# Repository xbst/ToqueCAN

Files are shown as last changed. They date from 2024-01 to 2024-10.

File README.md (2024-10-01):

# 

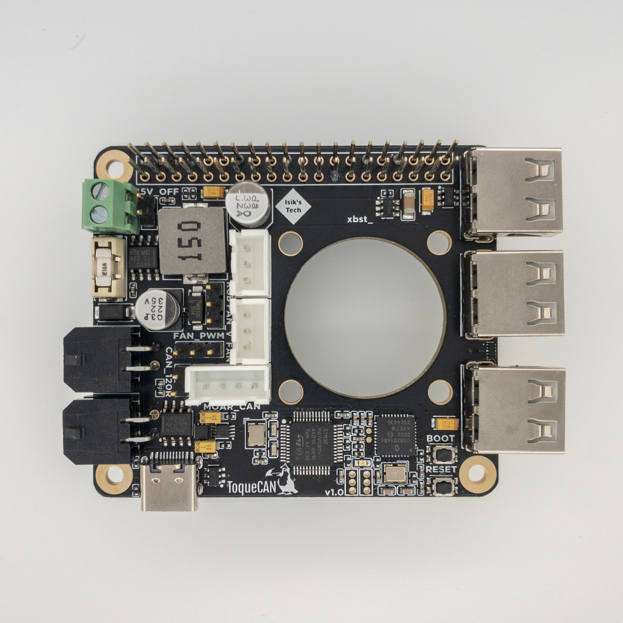
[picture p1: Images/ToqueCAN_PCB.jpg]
ToqueCAN PCB


ToqueCAN is an open-source Raspberry Pi toque* with:
- A CAN transceiver with 2x CAN connectors
- 3 port USB hub
- 24V to 5V 5A regulator for powering the Pi and USB devices
- Pi cooling fan (30mm or 40mm) mount with PWM speed control
- Neopixel control
- GPIO passthrough
- Supports Klipper and Candlelight firmwares

Designed for 3D printers with many CAN devices, 24V power and small electronics chambers.

*Almost like a hat, no EEPROM.

## YouTube Video
YouTube Video (https://youtu.be/QP4bZ6_RnH0)

## Purchasing a ToqueCAN
### Buy From Me
- Each PCB tested by me
- All connectors needed are included (if applicable)
- Supports the development of open-source projects like this
- Ships worldwide

#### United States
- [Isik's Tech](https://store.isiks.tech/products/toquecan)

### Resellers
- Each PCB tested by me
- All connectors needed are included (if applicable)
- Supports the development of open-source projects like this
#### United States
- [Amazon - Prime Shipping](https://www.amazon.com/dp/B0D33F7GBZ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)
- [West3D](https://west3d.com/products/toquecan-pi-toque-with-2xcan-and-24v-5v-regulator?_pos=1&_psq=Toque&_ss=e&_v=1.0)
#### Canada
- [Amazon - Ships from the US](https://www.amazon.ca/dp/B0D33F7GBZ)
#### European Union
- [Lab4450 - Portugal](https://lab4450.com/product/toquecan-pi-by-xbst_/)

### Other Trusted Vendors
These vendors source their PCBs from other sources, but are trusted vendors on Voron and Voron-related communities.

[TBD]

This project is licensed under [GPL v3](./LICENSE), meaning vendors are allowed to sell PCBs without paying me. If you'd like to support the development of this and future projects please consider [sponsoring](https://github.com/sponsors/xbst) me on GitHub. You can also subscribe on [Patreon](https://l.isiks.tech/patreon) or [YouTube](https://l.isiks.tech/member).

You can also use the included gerber files to order your own from a PCB manufacturer like [PCBWay](https://www.pcbway.com/setinvite.aspx?inviteid=374841) or [JLCPCB](https://jlcpcb.com/).
<br>

## [Instructions](./Docs/ToqueCAN-Manual.pdf)
Click the above link to download the ToqueCAN manual (PDF).

## YouTube

I am a YouTube content creator. If you want content about these projects & more, please consider [subscribing to my YouTube channel](https://www.youtube.com/channel/UClAWYmCkHjsbaX9Wz1df2mg).
<br>

If you feel like contributing to the development of this project and other projects like this you can sponsor me on [GitHub](https://github.com/sponsors/xbst), subscribe on [Patreon](https://l.isiks.tech/patreon) or [YouTube](https://l.isiks.tech/member).

## Notes
- Markdown files in this repository may contain Amazon Associate, Aliexpress affiliate, PCBWay affiliate, Jawstec affiliate, Polymaker affiliate links. I make a comission on qualifying purchases.
- This project does not come with any warranty, if you choose to build/use a PCB manufactured using published files in this repository, you are doing this at your own risk!
- If you want to sell PCBs manufactured using published files in this repository, you are allowed to, and you will not owe me any royalties. **You cannot claim that I endorse the sale**. You can check the license file for more information. However, if you **wish** to give me a share you can sponsor me on [GitHub](https://github.com/sponsors/xbst), subscribe on [Patreon](https://l.isiks.tech/patreon) or [YouTube](https://l.isiks.tech/member).

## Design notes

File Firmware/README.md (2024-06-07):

Only for Klipper in bridge mode. Follow the [documentation](../Docs/ToqueCAN-Manual.pdf) for more info.

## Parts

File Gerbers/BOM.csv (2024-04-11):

ID | Name | Designator | Footprint | Quantity | Manufacturer Part | Manufacturer | Supplier | Supplier Part | Price
1 | 10u | C17,C19,C13 | CAP-SMD_L3.2-W1.6-R-RD | 3 | TAJA106K016RNJ | AVX | LCSC | C7171 | 0.097
2 | 5.1kΩ | R7,R8 | R0402 | 2 | RC0402FR-075K1L | YAGEO(国巨) | LCSC | C105872 | 0.001
3 | 3.16kΩ | R10 | R0402 | 1 | 0402WGF3161TCE | UNI-ROYAL(厚声) | LCSC | C11462 | 0.001
4 | 43045-0401 | CAN1,CAN2 | CONN-TH_0430450400 | 2 | 43045-0401 | MOLEX | LCSC | C585880 | 0.689
5 | XH-4A-B | MOAR_CAN | CONN-TH_B4B-XH-A-BK-LF-SN | 1 | XH-4A | HCTL | LCSC | C37815 | 0.027
6 | PUSB3F96X_C2923351 | D5 | DFN2510-10_L2.5-W1.0-P0.50-BL | 1 | PUSB3F96X | TECH PUBLIC(台舟) | LCSC | C2923351 | 0.089
7 | USBLC6-2SC6_C2827654 | D4,D3 | SOT-23-6_L2.9-W1.6-P0.95-LS2.8-BL | 2 | USBLC6-2SC6 | TECH PUBLIC(台舟) | LCSC | C2827654 | 0.058
8 | U-A-24DD-W-5 | USB2,USB1,USB3 | USB-A-TH_U-A-24DD-W-5 | 3 | U-A-24DD-W-5 | 韩国韩荣 | LCSC | C530625 | 0.094
9 | 1uF | C20,C21 | CASE-A_3216 | 2 | CA45-A-35V-1uF-K | CEC(振华新云) | LCSC | C141744 | 0.089
10 | 100n | C22,C23,C24,C25,C26,C27,C3,C5,C7,C10,C11,C12 | C0402 | 12 |  |  | LCSC | C1525 | 0.001
11 | 0154010.DR | F1 | FUSE-SMD_L9.7-W5.0 | 1 | 0154010.DR | Littelfuse(美国力特) | LCSC | C206921 | 1.346
12 | B3B-XH-A-BK(LF)(SN) | FAN,RGB | CONN-TH_3P-P2.50_B3B-XH-A-BK-LF-SN | 2 | B3B-XH(LF)(SN) | JST | LCSC | C144394 | 0.089
13 | HDR-M-2.54_1x3 | FAN_PWM,FAN_V | HDR-M-2.54_1X3 | 2 |  |  | LCSC | C306138 | 0.2
14 | 10K 1% | R18,R1,R9 | R0402 | 3 |  |  | LCSC | C25744 | 0.001
15 | SN74LVC2G125DCUR | U4 | VSON8_L2.0-W2.3-P0.50-LS3.1-BL | 1 | SN74LVC2G125DCUR | TI(德州仪器) | LCSC | C21404 | 0.258
16 | LP5912-3.3DRVR | U7 | WSON-6_L2.0-W2.0-P0.65-TL-EP | 1 | LP5912-3.3DRVR | TI(德州仪器) | LCSC | C524780 | 0.695
17 | 8MHz | X1 | CRYSTAL-SMD_4P-L3.2-W2.5-BL-2 | 1 | 3TJ480000ZYLBC | JYJE(晶友嘉) | LCSC | C2924619 | 0.195
18 | 15uH | L1 | IND-SMD_L10.1-W11.6 | 1 | CKST1004-15uH/M | CENKER | LCSC | C3002687 | 0.262
19 | DB125-3.5-2P-GN-S | VIN | CONN-TH_2P-P3.50_L7.4-W7.0 | 1 | DB125-3.5-2P-GN-S | DIBO(地博电气) | LCSC | C466970 | 0.159
20 | 470R 1% | R16 | R0402 | 1 |  |  | LCSC | C25117 | 0.001
21 | HDR-M-2.54_1x2 | 5V_OFF,CAN_120R | HDR-M-2.54_1X2 | 2 |  |  | LCSC | C180247 | 0.022
22 | EVPAA202K | BOOT,RESET | KEY-SMD_4P-L3.5-W2.9-P1.48-LS4.3-TL | 2 | EVPAA202K | PANASONIC(松下) | LCSC | C79147 | 0.356
23 | 100uF | C1 | C1206 | 1 |  | SAMSUNG(三星) | LCSC | C15008 | 0.063
24 | 22u | C2 | CAP-D6.3×H5.5 | 1 | UWF1V220MCL1GB-W | Nichicon | LCSC | C2163072 | 0.157
25 | 330u | C14 | CAP-D6.3×H5.5 | 1 | EMZA6R3ARA331MF80G | NCC(Nippon Chemi-Con) | LCSC | C2165829 | 0.168
26 | 100nF | C4,C6 | C0402 | 2 | 0402B104K500NT | FH(风华) | LCSC | C110251 | 0.002
27 | 30pF | C8,C9 | C0603 | 2 | 0603CG300J500NT | FH(风华) | LCSC | C1658 | 0.003
28 | 20pF | C15,C16 | C0603 | 2 |  | SAMSUNG(三星) | LCSC | C1648 | 0.005
29 | LED-0603_B | CAN_MCU | LED0603_BLUE | 1 | 19-217/BHC-ZL1M2RY/3T | EVERLIGHT(台湾亿光) | LCSC | C72041 | 0.018
30 | SS34_C8678 | D1 | SMA_L4.3-W2.6-LS5.2-RD | 1 | SS34 | MDD | LCSC | C8678 | 0.023
31 | SS54_C22452 | D2 | SMA_L4.4-W2.8-LS5.4-R-RD | 1 | SS54 | MDD | LCSC | C22452 | 0.038
32 | 27R4 1% | R3,R4 | R0402 | 2 |  |  | LCSC | C31439 | 0.001
33 | 120Ω | R2 | R0603 | 1 | FRC0603F1200TS | FOJAN | LCSC | C2906988 | 0.001
34 | 10Ω | R5 | R0402 | 1 | 0402WGF100JTCE | UNI-ROYAL(厚声) | LCSC | C25077 | 0.001
35 | 1.5kΩ | R6 | R0402 | 1 | 0402WGF1501TCE | UNI-ROYAL(厚声) | LCSC | C25867 | 0.001
36 | 36kΩ | R11,R12,R13,R14 | R0402 | 4 |  | UNI-ROYAL(厚声) | LCSC | C43676 | 0.001
37 | 12kΩ | R15 | R0402 | 1 |  | UNI-ROYAL(厚声) | LCSC | C25752 | 0.001
38 | 15kΩ | R17 | R0402 | 1 |  | UNI-ROYAL(厚声) | LCSC | C25756 | 0.001
39 | TPS5450DDAR | U1 | SOP-8_L4.9-W3.9-P1.27-LS6.0-BL-EP | 1 | TPS5450DDAR | TI(德州仪器) | LCSC | C114425 | 0.772
40 | STM32F072C8T6 | U2 | LQFP-48_L7.0-W7.0-P0.50-LS9.0-BL | 1 | STM32F072CBT6 | ST(意法半导体) | LCSC | C81720 | 1.718
41 | SN65HVD232DR | U3 | SOIC-8_L5.0-W4.0-P1.27-LS6.0-BL | 1 | SN65HVD232DR | TI(德州仪器) | LCSC | C30530 | 0.966
42 | USB2514B-I/M2 | U5 | SQFN-36_L6.0-W6.0-P0.50-BL-EP | 1 | USB2514B-I/M2 | MICROCHIP(美国微芯) | LCSC | C220679 | 2.092
43 | AP22653W6-7 | U6 | SOT-23-6_L2.9-W1.6-P0.95-LS2.8-BR | 1 |  | DIODES(美台) | LCSC | C2158037 | 0.238
44 | USB3.1C16PFSMT | USBCIN | USB-C-SMD_TYPE-C-USB-17 | 1 | - | LCSC | LCSC | C167321 | 0.358
45 | 24MHz | X2 | CRYSTAL-SMD_4P-L3.2-W2.5-BL | 1 |  | TAE(雅晶鑫) | LCSC | C362340 | 0.062
46 | HDR-TH_40P-P2.54-V-F-R2-C20-S2.54-2 | U8 | HDR-TH_40P-P2.54-V-F-R2-C20-S2.54-2 | 1 | 2.54-2*20P母长PC104 | BOOMELE(博穆精密) | LCSC | C35165 | 0.943

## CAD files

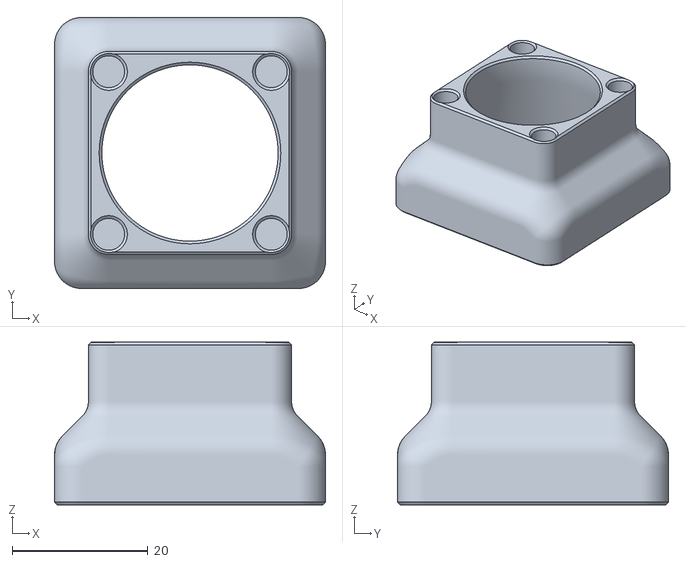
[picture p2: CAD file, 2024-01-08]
Fan-Mounts/40mm_Fan_Holder.stl
40.0 x 40.0 x 24.0

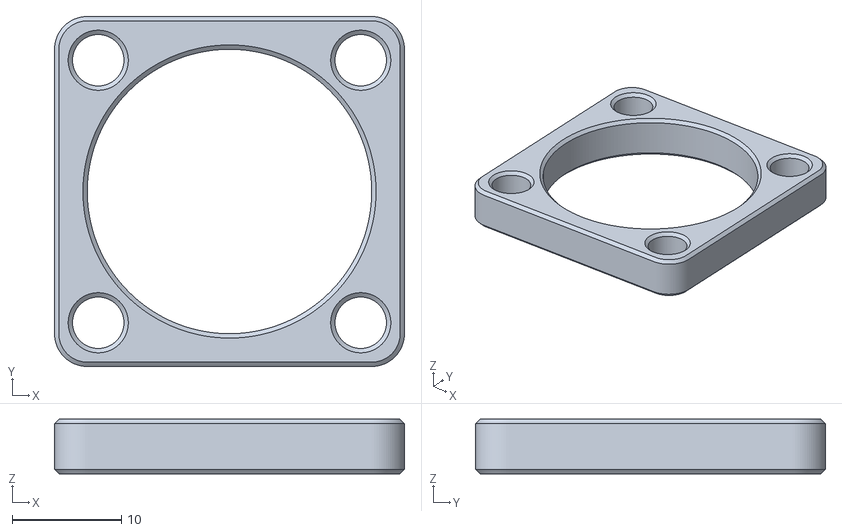
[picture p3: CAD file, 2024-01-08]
Fan-Mounts/30mm_Fan_Holder.stl
32.0 x 32.0 x 5.00

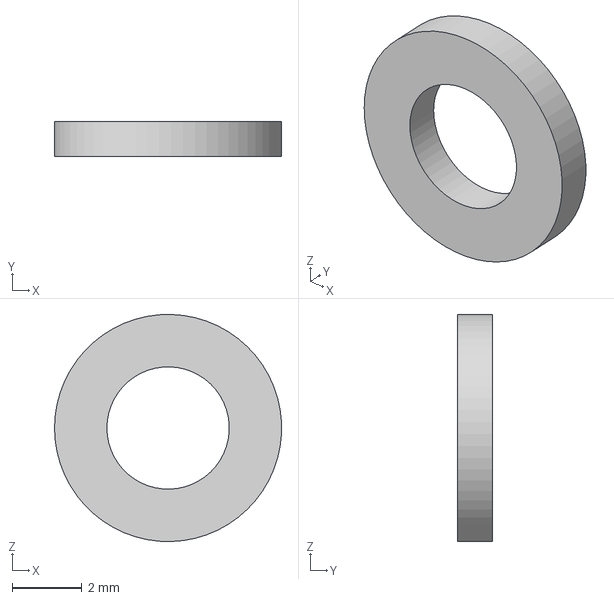
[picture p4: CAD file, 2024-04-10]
CAD/M3-Washer.step
6.50 x 1.00 x 6.50 mm

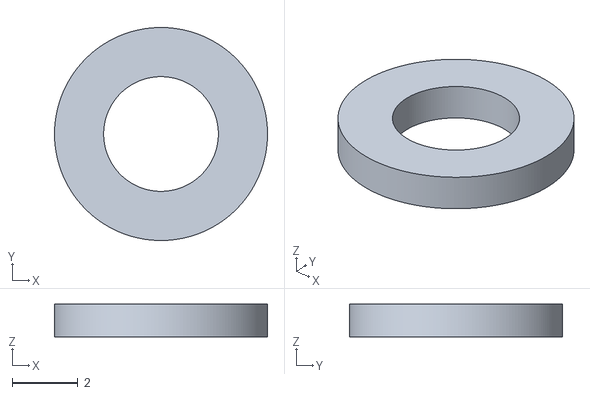
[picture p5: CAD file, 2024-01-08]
Fan-Mounts/40mm_Fan_M3_Washer.stl
6.50 x 6.50 x 1.00

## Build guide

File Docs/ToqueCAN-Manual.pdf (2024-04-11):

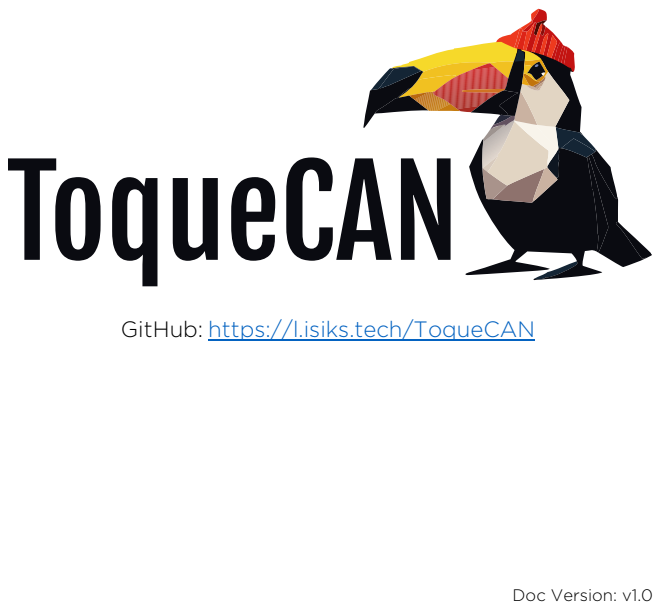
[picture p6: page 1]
Doc Version: v1.0

GitHub: https://l.isiks.tech/ToqueCAN

ToqueCAN Manual

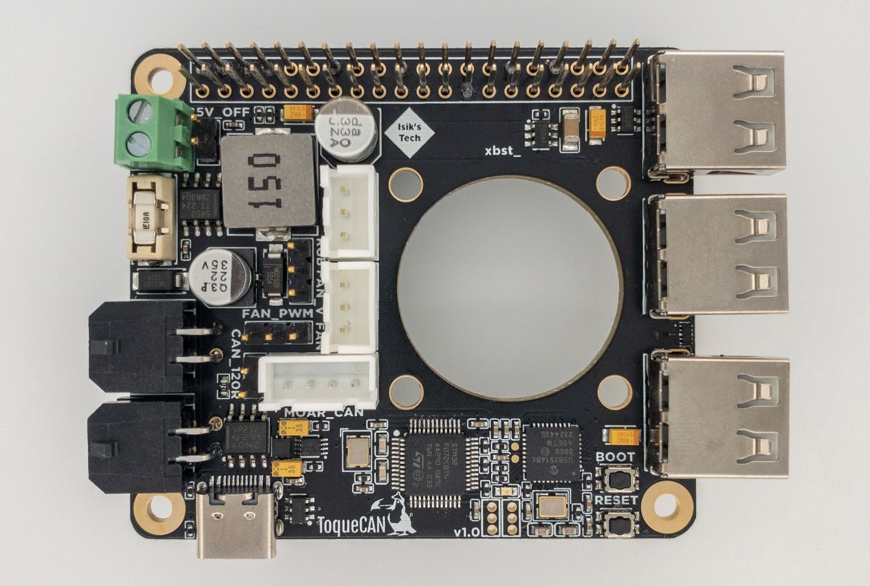
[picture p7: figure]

## ToqueCAN Features

- Pi toque, sits on a Raspberry Pi with GPIO passthrough
- USB C to Pi’s front USB
- 3 port USB hub (+1 used for CAN)
- All USB connectors are ESD protected
- STM32F072 MCU with SN65HVD232 transceiver for 1M CAN
- 2x CAN outputs with jumpers for proper termination, expansion connector for more
- Supports Candlelight and Klipper (in bridge mode) firmware
- If Klipper firmware is used, optional 5V Neopixel control
- Powers the Pi and USB ports with its 5V 5A converter, can be turned off
- USB power limited to 2.1A so Pi always gets enough power
- 24V power input for CAN connectors and 5V regulator, fused
- Cutout for a 30mm fan for cooling the Pi, 5V or 24V
- Optional PWM RPM control for the fan, from Pi’s GPIO or MCU if running Klipper in bridge mode

## Parts Needed

These parts may or may not come with your PCB if you buy them from a vendor. Isik’s Tech purchases will include these, except the fan, fan fasteners and the USB Cable.

Note: AliExpress affiliate / Amazon associate links above. Purchases made using the above links help me continue developing open-source projects like this without additional cost to you. Thanks!

Part | US | AliExpress
ToqueCAN PCB | Check GitHub (https://github.com/xbst/ToqueCAN) ToqueCAN USB Adapter (Optional)

2x10 Pin Tall Long Legged Female Pin Header
(Might be soldered on the ToqueCAN
already)
Amazon (https://amzn.to/47fm4fx) | AliExpress (https://s.click.aliexpress.com/e/_DeyJl73)
2x Molex Micro-Fit 2x2 Male Connector | Mouser (https://www.mouser.com/ProductDetail/Molex/43025-0400?qs=UeCeOHRHQeYw098k%2FAKI8Q%3D%3D) | AliExpress (https://www.aliexpress.us/item/3256802961371687.html) 8x Molex Micro-Fit Female Pins | Mouser

2x 3-Pin JST-XH Male Connector
1x 4-Pin JST-XH Male Connector | Amazon (https://amzn.to/3TNl7Ie) | AliExpress (https://s.click.aliexpress.com/e/_DncmKup)
10x JST-XH Pins
5x Pin Header Jumpers | Amazon (https://amzn.to/3TI7FFS) | AliExpress (https://s.click.aliexpress.com/e/_DdLVsTJ)
3x M2.5 14mm Male/Female Standoffs | - | AliExpress (https://s.click.aliexpress.com/e/_DmbOjHr)
4x M2.5 6mm (or similar) Screws | Amazon (https://amzn.to/3RFQiT9) | AliExpress (https://s.click.aliexpress.com/e/_DcQcd2Z)
4x M2.5x4.2x3.6 Threaded Inserts (Optional,
for Pi mounts) | - | AliExpress (https://s.click.aliexpress.com/e/_De15OtF)
4x M3x5.0x4.0 Threaded Inserts (30mm Fan,
8x for 40mm Fans) | Amazon (https://amzn.to/41HMZQi) | AliExpress (https://s.click.aliexpress.com/e/_DkbY5o5)
4x M3 Screw (Fan) (Fan height + few mm
long) (+4x M3 6mm screw for 40mm Fan) | Amazon (https://amzn.to/41F3FYz) | AliExpress (https://s.click.aliexpress.com/e/_Dm8UE2H)
30mm (or 40mm) PWM Fan | Amazon (https://amzn.to/3TDGHis) | AliExpress (https://s.click.aliexpress.com/e/_Dn2Eguv)
Short USB A to C Cable | Amazon (https://amzn.to/43nCH8N) | AliExpress (https://s.click.aliexpress.com/e/_DlX1gHB)

## Step 1: Soldering Pins

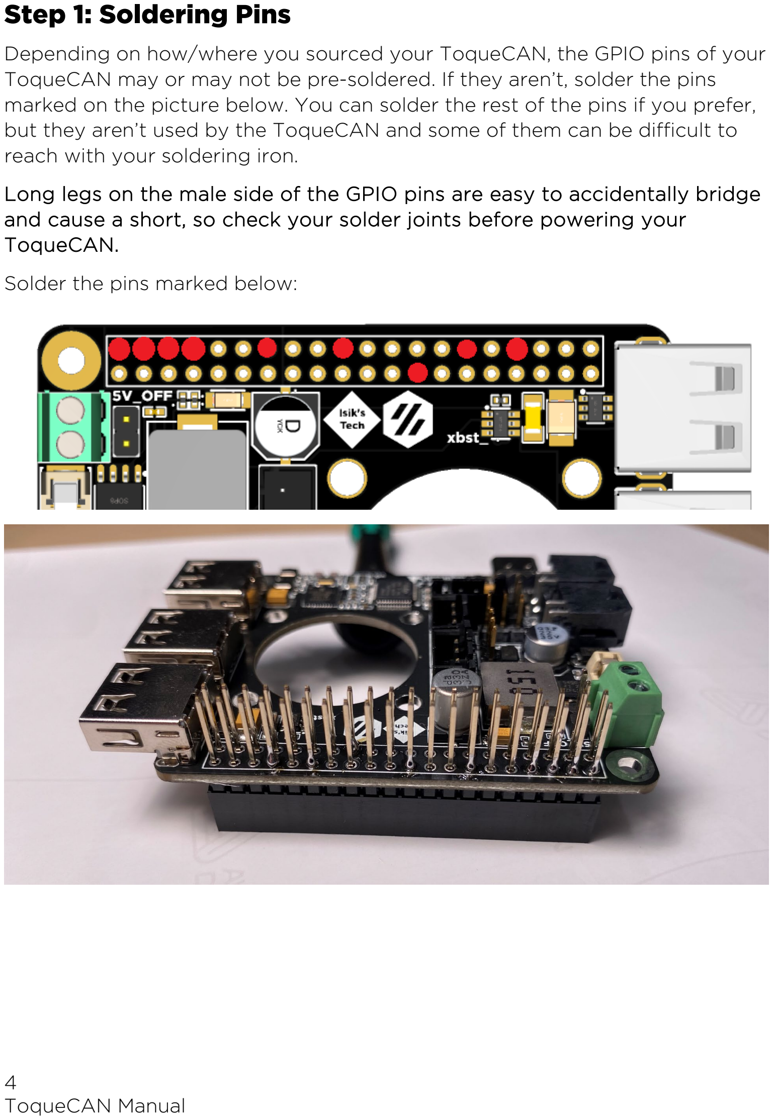
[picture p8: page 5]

Depending on how/where you sourced your ToqueCAN, the GPIO pins of your ToqueCAN may or may not be pre-soldered. If they aren’t, solder the pins marked on the picture below. You can solder the rest of the pins if you prefer, but they aren’t used by the ToqueCAN and some of them can be difficult to reach with your soldering iron.
Long legs on the male side of the GPIO pins are easy to accidentally bridge and cause a short, so check your solder joints before powering your ToqueCAN.
Solder the pins marked below:

## Step 2: Fan Installation

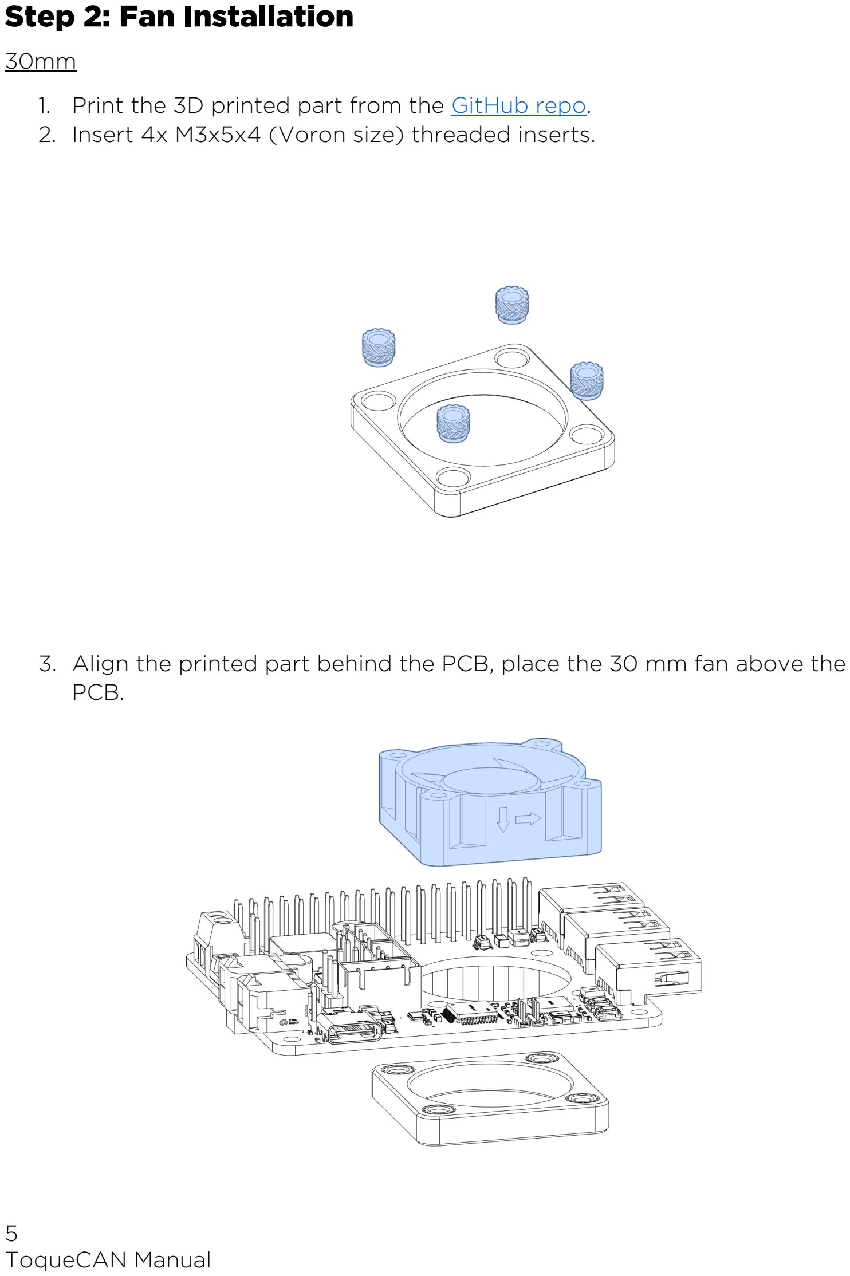
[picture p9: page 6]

30mm
1. Print the 3D printed part from the GitHub repo. (https://github.com/xbst/ToqueCAN/blob/master/Fan-Mounts/30mm_Fan_Holder.stl)
2. Insert 4x M3x5x4 (Voron size) threaded inserts.
3. Align the printed part behind the PCB, place the 30 mm fan above the PCB.

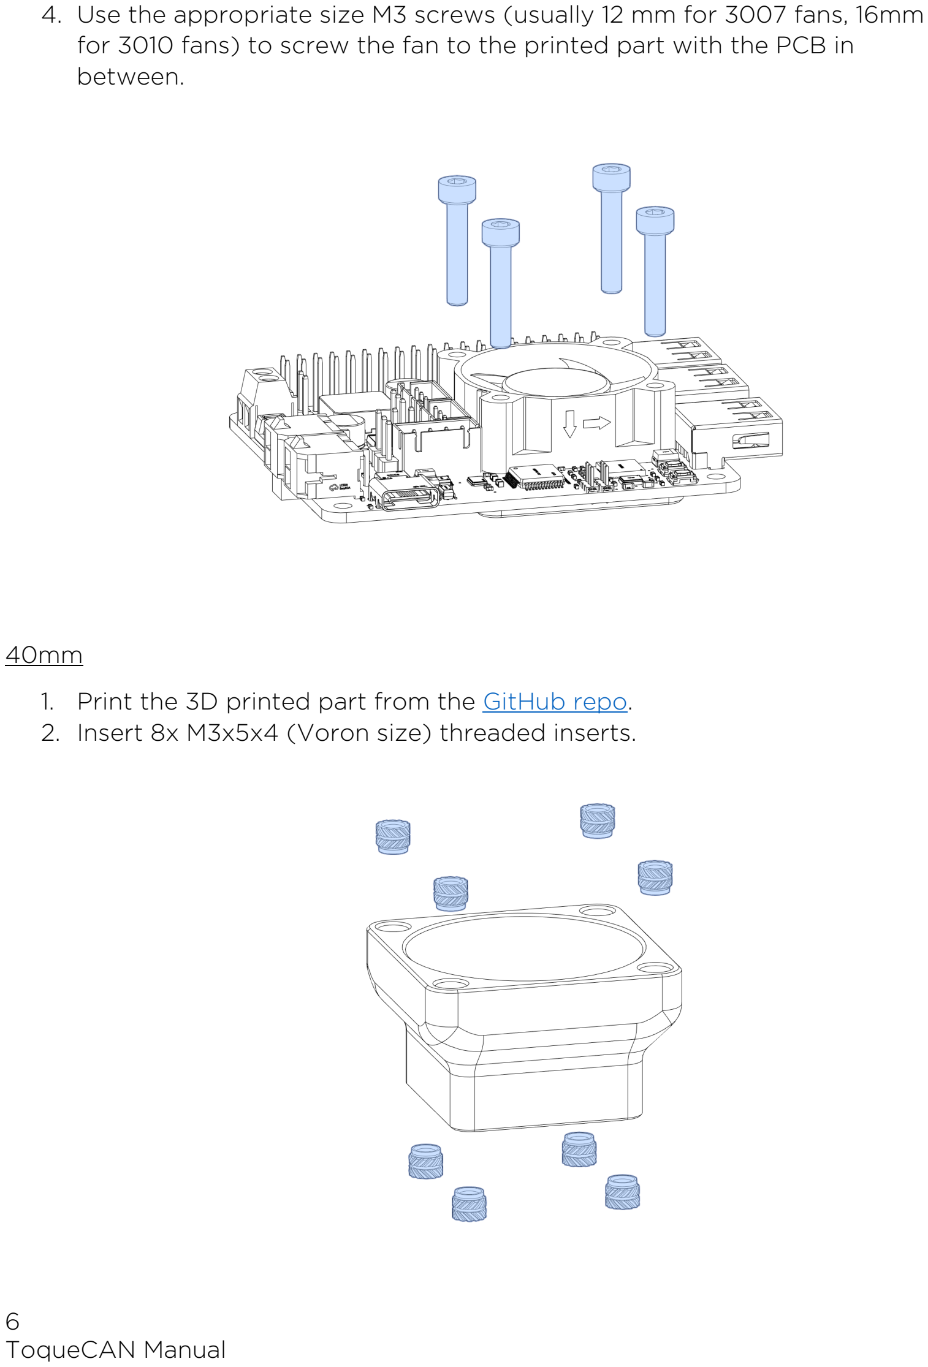
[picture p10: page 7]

4. Use the appropriate size M3 screws (usually 12 mm for 3007 fans, 16mm for 3010 fans) to screw the fan to the printed part with the PCB in between.

40mm
1. Print the 3D printed part from the GitHub repo. (https://github.com/xbst/ToqueCAN/blob/master/Fan-Mounts/40mm_Fan_Holder.stl)
2. Insert 8x M3x5x4 (Voron size) threaded inserts.

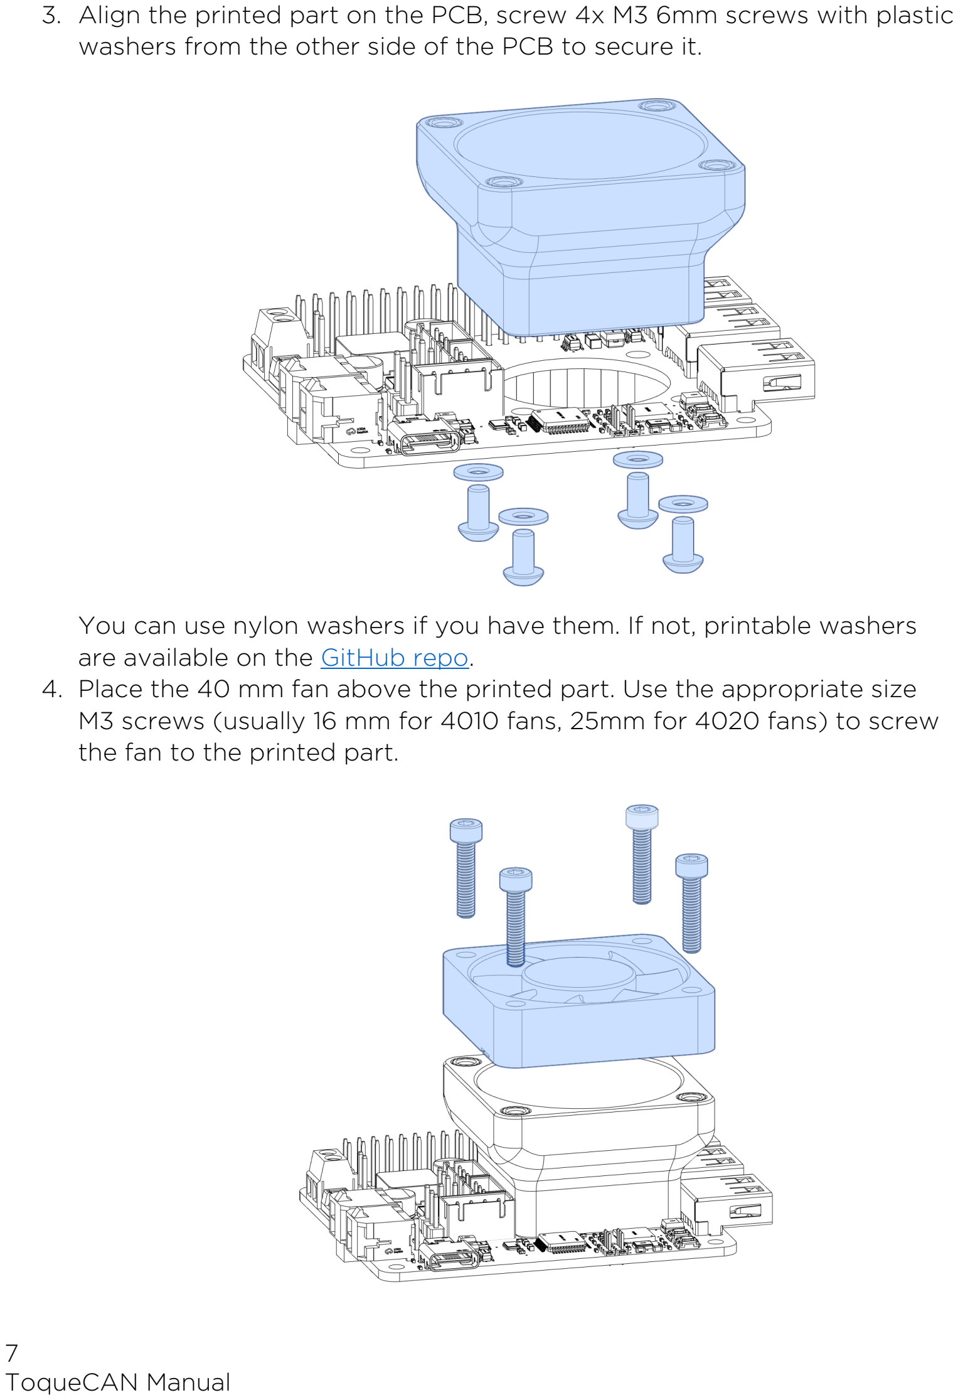
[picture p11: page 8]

3. Align the printed part on the PCB, screw 4x M3 6mm screws with plastic washers from the other side of the PCB to secure it.

You can use nylon washers if you have them. If not, printable washers are available on the GitHub repo. (https://github.com/xbst/ToqueCAN/blob/master/Fan-Mounts/40mm_Fan_M3_Washer.stl)
4. Place the 40 mm fan above the printed part. Use the appropriate size M3 screws (usually 16 mm for 4010 fans, 25mm for 4020 fans) to screw the fan to the printed part.

## Step 3: ToqueCAN on Pi Installation

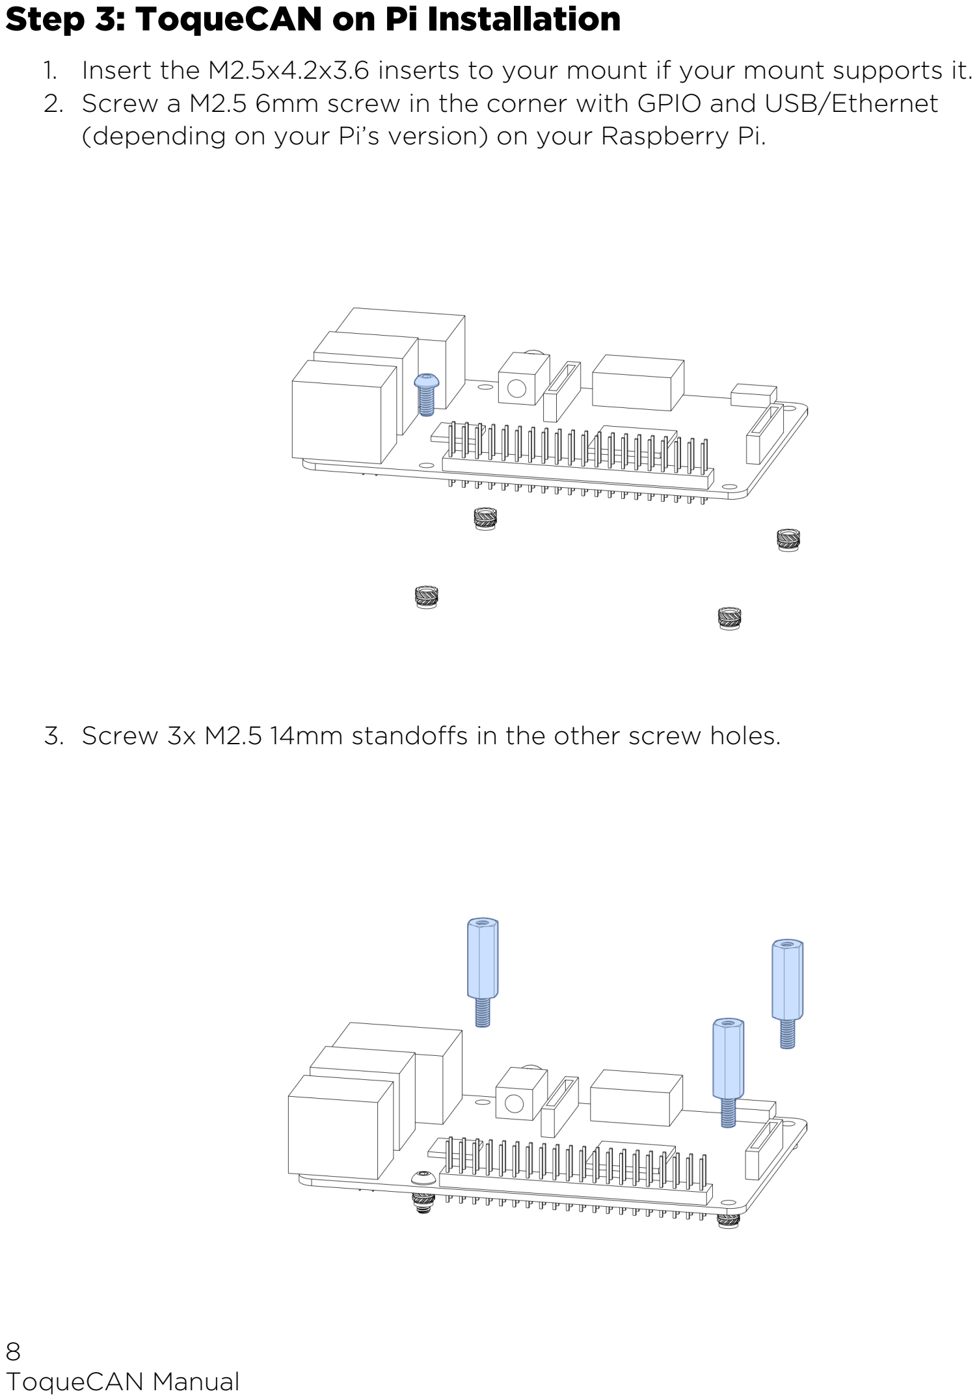
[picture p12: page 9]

1. Insert the M2.5x4.2x3.6 inserts to your mount if your mount supports it.
2. Screw a M2.5 6mm screw in the corner with GPIO and USB/Ethernet (depending on your Pi’s version) on your Raspberry Pi.
3. Screw 3x M2.5 14mm standoffs in the other screw holes.

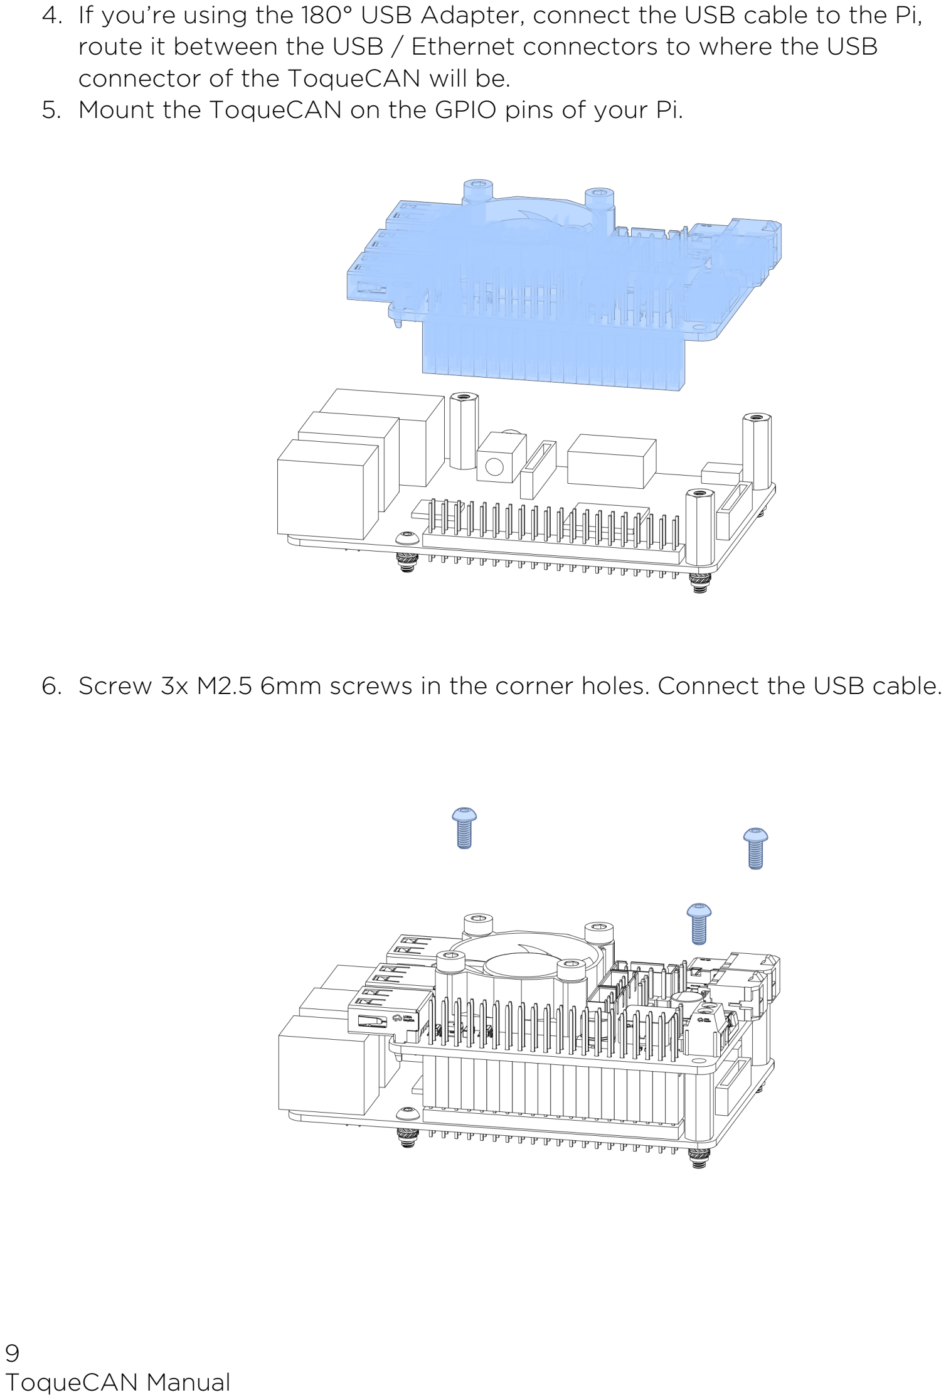
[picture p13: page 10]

4. If you’re using the 180° USB Adapter, connect the USB cable to the Pi, route it between the USB / Ethernet connectors to where the USB connector of the ToqueCAN will be.
5. Mount the ToqueCAN on the GPIO pins of your Pi.
6. Screw 3x M2.5 6mm screws in the corner holes. Connect the USB cable.

## Step 4: Jumpers

There are 5 sets of jumpers on the ToqueCAN. 3 more commonly adjusted ones are highlighted in the image below:

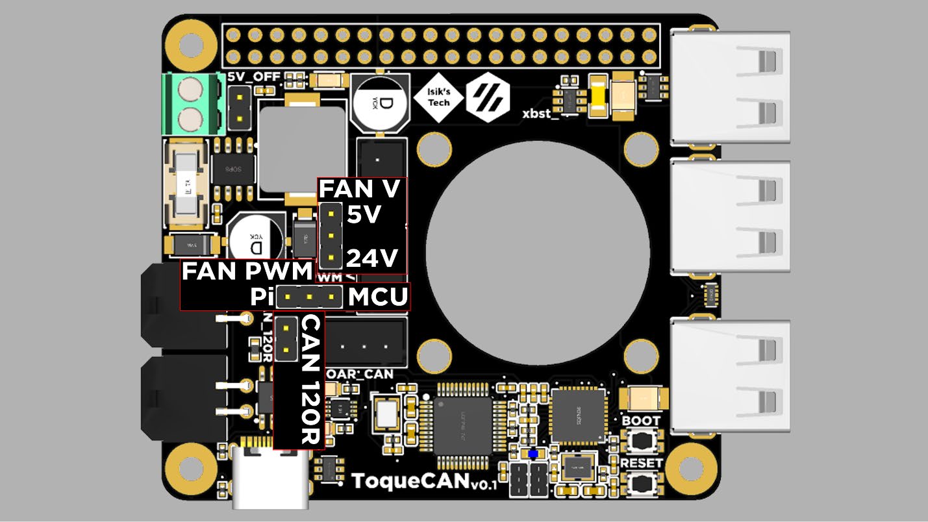
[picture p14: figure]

Jumpers:
- 5V_OFF: Turns off the 5V regulator on the PCB. Leave unpopulated for ToqueCAN to generate 5V for the Raspberry Pi, USB devices and other devices powered by the 5V rail.
- MOAR_CAN: This is a jumper header and an expansion connector in one. Its usage is explained later in this document. Populate with 2x jumpers for using the Microfit CAN outputs only.
- CAN_120R: The 120Ω termination resistor for CAN bus. Populate it if you are connecting 1 CAN device to the Microfits, don’t populate if you’re using both. For its use with MOAR_CAN, refer to that section of this document.
- FAN_PWM: The PWM source for the 30/40mm fan, if you are using a PWM capable fan. This lets you control the fan’s speed. You need to use Pi’s control if you are using Candlelight as your CAN firmware, with Klipper in bridge mode you can use the Pi or the MCU.
- FAN_V: Voltage of the 30/40mm fan. 5V from the regulator or 24V from the power input.

## Step 5: Connecting the FAN & (Optionally) Neopixels

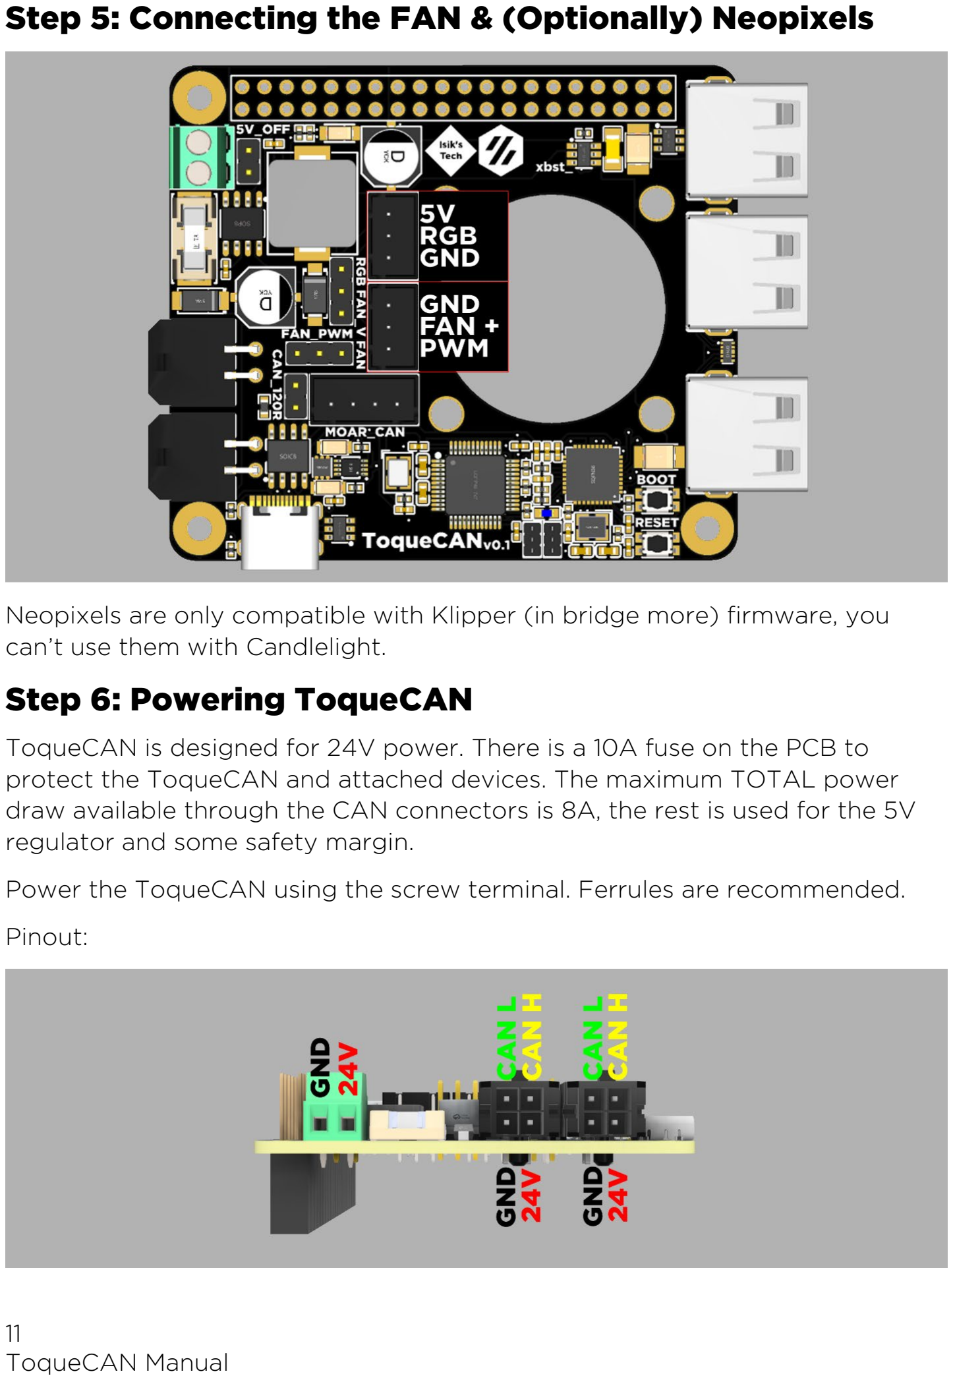
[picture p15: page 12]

Neopixels are only compatible with Klipper (in bridge more) firmware, you can’t use them with Candlelight.

## Step 6: Powering ToqueCAN

ToqueCAN is designed for 24V power. There is a 10A fuse on the PCB to protect the ToqueCAN and attached devices. The maximum TOTAL power draw available through the CAN connectors is 8A, the rest is used for the 5V regulator and some safety margin.
Power the ToqueCAN using the screw terminal. Ferrules are recommended. Pinout:

## Step 7: Firmware Flashing

Candlelight
1. SSH into your Raspberry Pi.
2. Install dependencies:
sudo apt-get install cmake gcc-arm-none-eabi git dfu-util
3. Download the firmware: (By Lab4450)
cd ~
git clone https://github.com/lab4450/u2c
cd u2c
4. On your ToqueCAN, hold down the BOOT button, while holding it down press the RESET button, then release the BOOT button. The blue LED should turn on.
5. Use lsusb to verify that the ToqueCAN’s MCU (STM32F072) is in DFU mode.
6. Flash the firmware:
sudo dfu-util -D candleLight_fw.bin -d 0483:df11 -a 0 -s 0x08000000:leave
Klipper (Bridge Mode)
1. SSH into your Raspberry Pi.
2. Navigate to the Klipper directory: cd ~/klipper
3. Clean old build data: make clean
4. Configure the build settings: make menuconfig Use these settings:

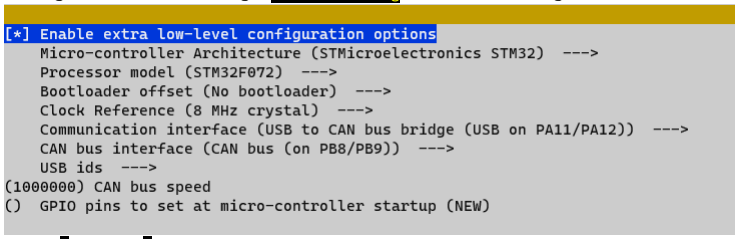
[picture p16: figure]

5. Press Q to exit, Y to save.
6. Plug in your ToqueCAN while holding down the BOOT button.
7. Use lsusb to verify that the ToqueCAN’s MCU (STM32F072) is in DFU mode.
8. Flash the firmware:
make flash FLASH_DEVICE=0483:df11

## Step 8: Klipper Can Bus Prep & CAN PCBs

1. If this is your first-time enabling CAN Bus on this printer, you need to enable the CAN network on your host device (Pi). To do this, you need to create a file. Use this command: (SSH)
sudo nano /etc/network/interfaces.d/can0
Add this to the file you’re creating:
allow-hotplug can0
iface can0 can static
bitrate 1000000
up ifconfig $IFACE txqueuelen 1024 Press CTRL + X, then Y and ENTER to save & exit.
2. Shutdown your host using: sudo shutdown now
3. When the LEDs on the Pi stop blinking, turn off your power supply to disconnect your ToqueCAN from power.
4. Crimp the microfits on the wires of your CAN devices. Insert them to the microfit connector according to this pinout:

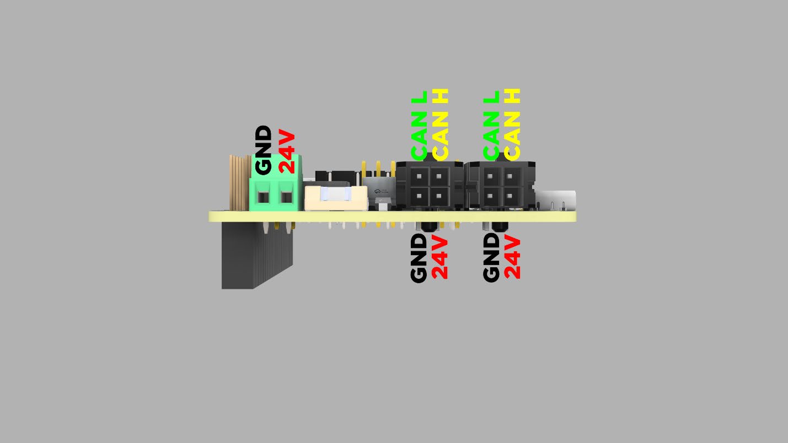
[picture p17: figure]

5. Plug in your CAN devices.
6. Turn your power supply back on and SSH into your Pi.
7. If your CAN devices aren’t flashed with CanBoot/Katapult and/or Klipper yet, use their instructions to flash them.
8. Use this Klipper script to check if your CAN devices are detected and what their UUIDs are:
~/klippy-env/bin/python ~/klipper/scripts/canbus_query.py can0

## Step 9A: Pi PWM Fan Control

This step is optional. If you want to use your Raspberry Pi to control your PWM fan, and configured the jumpers correctly for this, follow these instructions:
1. SSH into your Raspberry Pi.
2. sudo raspi-config
3. Enter Performance Options
4. Enter Fan
5. Select Yes
6. Enter 14
7. Adjust the trigger temperature.
8. When done, exit with Finish, and reboot.

## Step 9B: Klipper Bridge Mode Config

This step is optional. You only need to follow this step if you are using Klipper in bridge mode as your ToqueCAN’s firmware and want to use Klipper to control the PWM fan and Neopixels.
1. Download the config file from the ToqueCAN GitHub repo. (https://github.com/xbst/ToqueCAN/blob/master/Firmware/toquecan.cfg)
2. Upload this to your config folder
3. Open it and edit your canbus_uuid. You can use the script from the last step of Step 8 to find what your UUID is. Save and close (don’t restart yet).
4. Open your printer.cfg. Add this line:
[include toquecan.cfg]
Save and close. Restart Klipper.

## MOAR_CAN Connector

This is an optional connector for adding more CAN bus devices. This requires an external PCB or similar solution to wire all the CAN bus devices together. Currently there isn’t a ToqueCAN solution for this. This section explains how it’s intended to be used.
Here is a diagram of how the CAN connectors, termination resistor, transceiver and the MOAR_CAN connector are wired on the PCB:

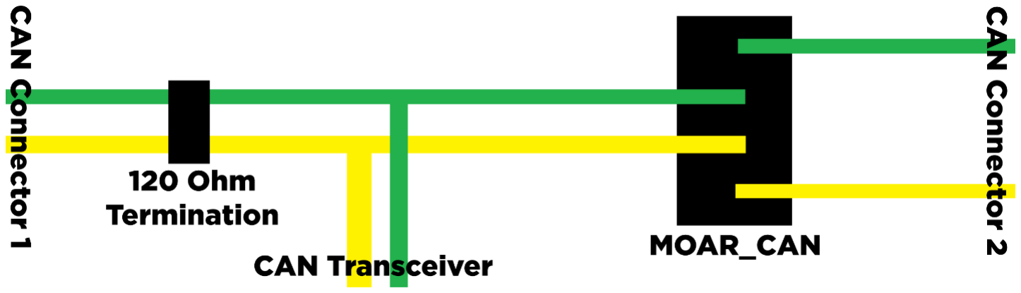
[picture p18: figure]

As you can see, the MOAR_CAN connector is between the CAN connectors. Populating it with 2 jumpers joins the CAN wires of both connectors so they’re on the same bus. If using both connectors, the termination resistor header isn’t jumped, since the transceiver of the ToqueCAN is in the middle so the CAN bus doesn’t need termination. If using only one CAN device, the termination resistor header should be jumped as now the ToqueCAN is at one end of the CAN bus.
But what if you want moar CAN bus devices? That’s what this connector is for. You simply need to wire it in a way that goes to your extra CAN devices and comes back.

For example:

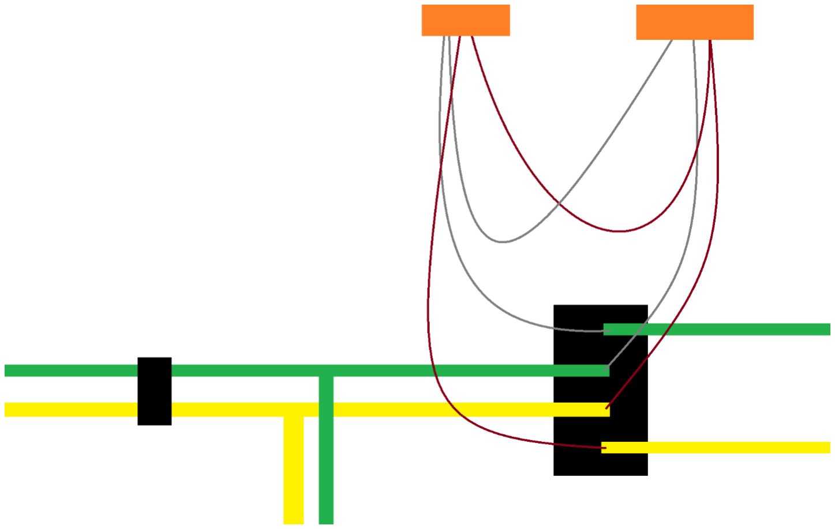
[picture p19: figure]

In this diagram 2 more CAN devices are connected to the same bus. Wires are connected to the middle pins of the MOAR_CAN connector, a CAN bus device to these wires. Then daisy chained from that device to another device. Finally, it’s daisy chained again to the outer pins of the MOAR_CAN connector on the ToqueCAN PCB. In this example you connected 4 devices to the CAN bus of the ToqueCAN, so in total there are 5 devices on the bus (including ToqueCAN). Theoretically you can add even more devices, but you will eventually hit a limit where your devices can’t communicate well.
A simple breakout PCB with some 4-pin JST-XH connectors can act as a hub for this to make daisy chaining easier.
Also remember to make sure the first and last CAN devices on the bus should have a 120Ω termination resistor, and none of the devices in between should have that.
Another thing to keep in mind is, your other CAN devices should share the same GND, so you either need to power them from the same source or tie the GNDs together.

## Chips & Specs

ToqueCAN
Power In | 24V
Fuse | 10A (Replacement) (https://www.mouser.com/ProductDetail/Littelfuse/0453010.MR?qs=OiFqjYYehYgCU5zYymAw5w%3D%3D)
Powers | CAN Outs 5V Regulator Optionally (Jumper), Fan
5V Regulator | TI TPS5450
Power Out | 5V 5A
Powers | Raspberry Pi (Through GPIO) 3.3V Regulator USBs (Limited to 2.1A, D.I. AP22653) Optionally (Jumper), Fan Neopixels
3.3V Regulator | TI LP5912-3.3
Power Out | 3.3V 500mA
Powers | USB Hub CAN MCU CAN Transceiver TI SN74LVC2G125
USB Hub | Microchip USB2514B-I/M2
USB In From | USB C
USB 1-3 To | USB A Connectors
USB 4 To | CAN MCU
CAN MCU | STM32F072C8T6
Firmware | Candlelight or Klipper in Bridge Mode
Connects To | CAN Transceiver (TX: PB9 RX: PB8) USB Hub (PA11/PA12) Neopixel (PA3, Through SN74LVC) Fan PWM (Jumper, PA2, Through SN74LVC)
CAN Transceiver | TI SN65HVD232
Speed | 1M
PCB Size | 56.5 x 65.0 mm
PCB Layer Count | 4

## Debugging

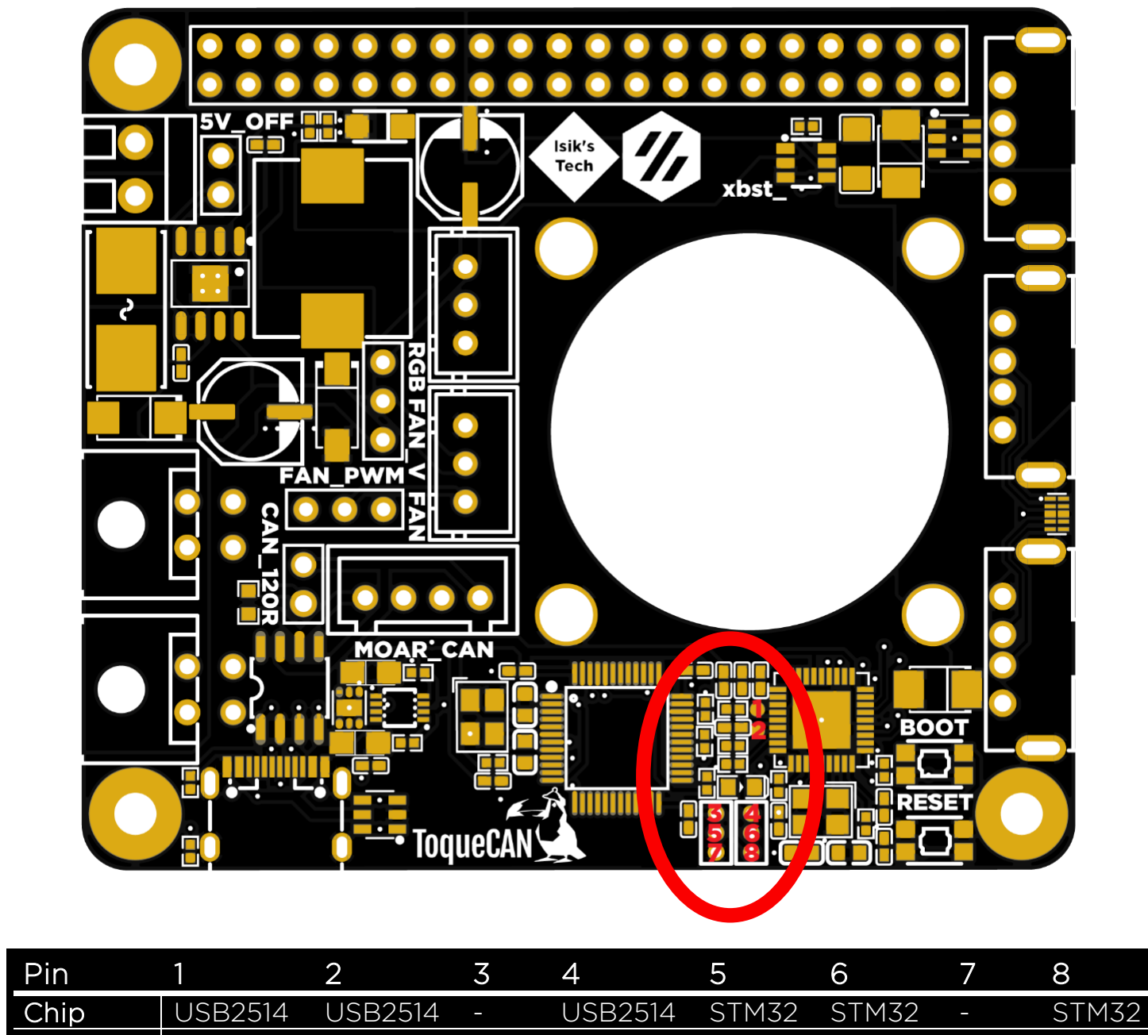
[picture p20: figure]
Pin; Chip; USB2514; STM32

Function | SDA | SCL | 3.3V | Reset | Reset | SWDIO | GND | SWCLK

Pins 3,5,6,7,8 can be used to flash new firmware to bricked (DFU not working) STM32F072 MCUs, or to access other ST-Link features. You can use the buttons for BOOT0 and RESET.
Pins 1,2,3,4,7 can be used to flash new firmware to the USB hub controller (USB2514B-I/M2) via I²C, or to reset it.

## Schematic

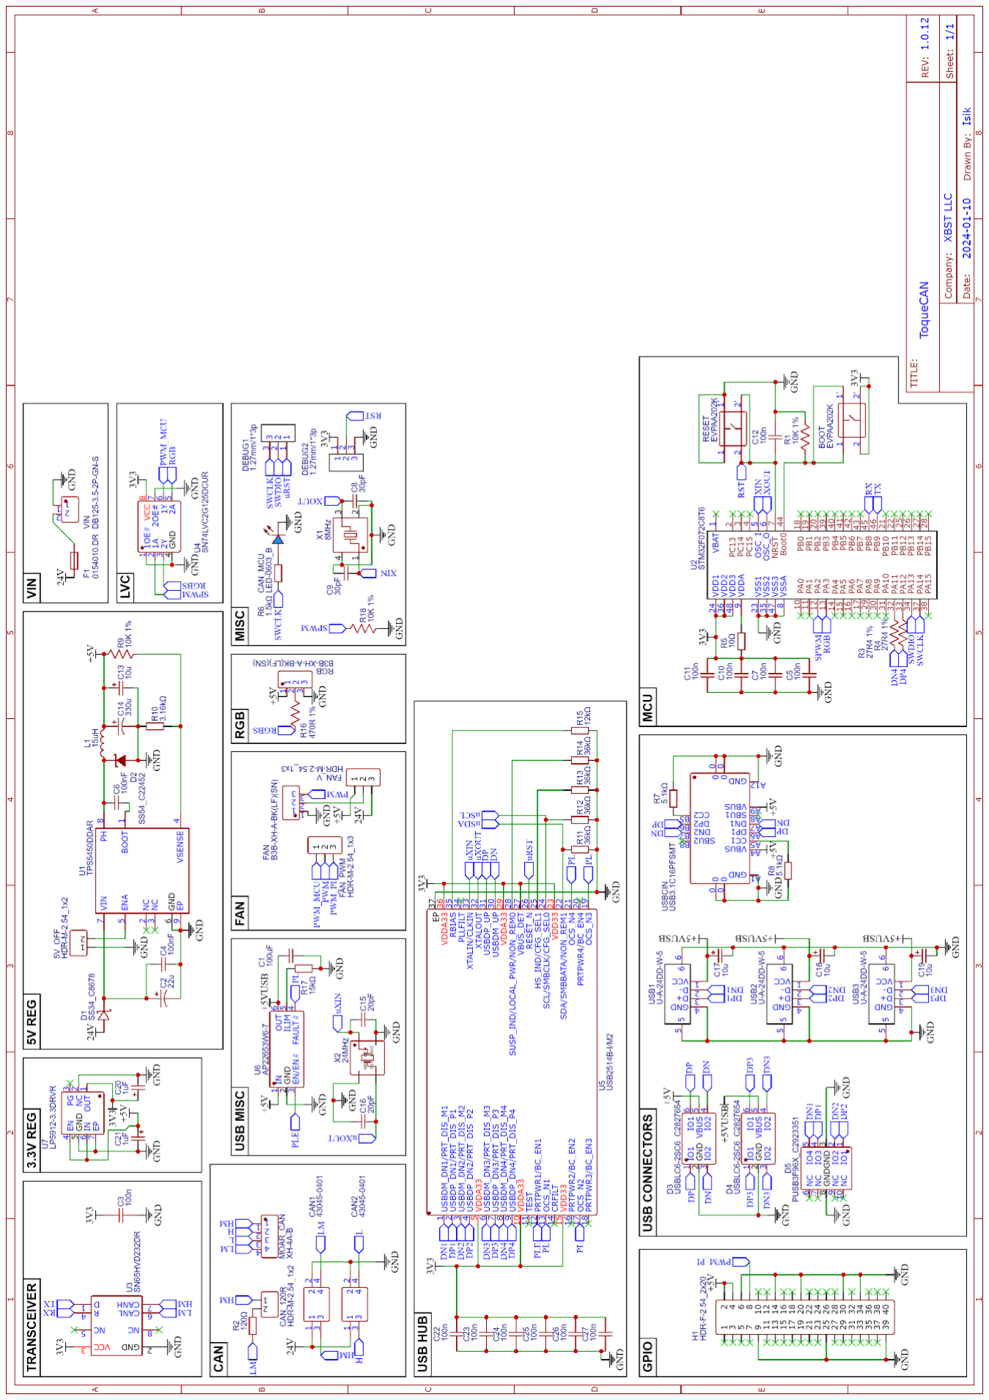
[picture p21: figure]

## More Resources

- Klipper CAN Bus Docs: https://www.klipper3d.org/CANBUS.html
- Klipper CAN Bus Troubleshooting: https://www.klipper3d.org/CANBUS_Troubleshooting.html
- Lab4450 U2C Candlelight Firmware: https://github.com/lab4450/u2c
- GitHub Repository of the Project: https://l.isiks.tech/ToqueCAN

## Thanks

- Doc
- Le0n (logo)
- Thebrakshow
- Esoterical
- alexz
- Kyleisah
- whoppingpochard

## Isik – xbst_

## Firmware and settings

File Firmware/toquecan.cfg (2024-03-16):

[mcu toquecan]
canbus_uuid: # enter CAN UUID

[temperature_fan pifan]
pin: toquecan:PA2
sensor_type: temperature_host
off_below: 0.5
min_temp: 10
max_temp: 90
target_temp:50
control: watermark

[neopixel piled]
pin: toquecan:PA3
color_order: GRBW

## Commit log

2024-01-08 Fan Mounts
    [30mm_Fan_Holder.stl, 40mm_Fan_Holder.stl, 40mm_Fan_M3_Washer.stl]
2024-03-16 Remove Flex gerbers
2024-03-16 Remove Flex PCB source (working on new solution)
2024-03-21 Updated PCB files
2024-04-10 New CAD
    [M3-Washer.step]
2024-04-10 USB Adapter Gerbers
    [BOM.csv, PNP.csv]
2024-04-11 Update part numbers
    [BOM.csv, PNP.csv]
2024-04-11 Added bottom layer assm (GPIO pins, in case you want them pre-soldered)
    [BOM.csv, PNP.csv]
2024-06-07 Move USB PCB to new repo
    [BOM.csv, PNP.csv]
